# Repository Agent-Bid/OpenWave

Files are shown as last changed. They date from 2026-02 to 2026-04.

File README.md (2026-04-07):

# OpenWave

This is an attempt to make an open-source, modern(ish) digital audio player using commonly available parts today with a simple menu-based operating system shell.

## Firmware Build Instructions

This project uses [PlatformIO](https://platformio.org/) for firmware development. The project is being developed with an ESP32 Devkit V1 (esp32dev).

### Prerequisites
* [PlatformIO CLI](https://docs.platformio.org/en/latest/core/index.html)
* Or [PlatformIO IDE - VSCode](https://docs.platformio.org/en/latest/integration/ide/vscode.html)

### Building
1. Navigate to the firmware directory: `cd Firmware/OpenWave_Firmware`
2. Resolve dependencies and build project: `pio run`

### Uploading
1. Connect the ESP32 board via USB and run: `pio run -t upload`
2. To monitor serial from the board: `pio device monitor`

## Hardware Used
All software tested on:
1. ESP32 Devkit V1
2. Adafruit VS1053b Breakout
3. SSD1306 OLED

Custom 4 layer PCB designed in KiCad
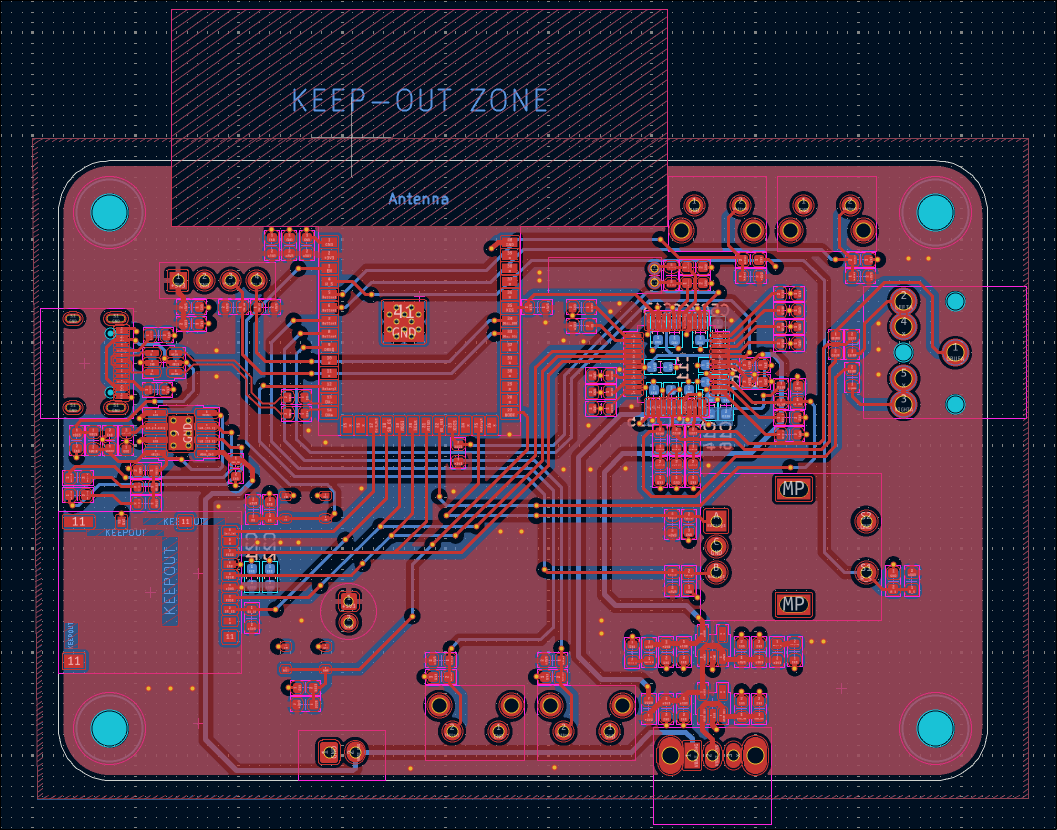
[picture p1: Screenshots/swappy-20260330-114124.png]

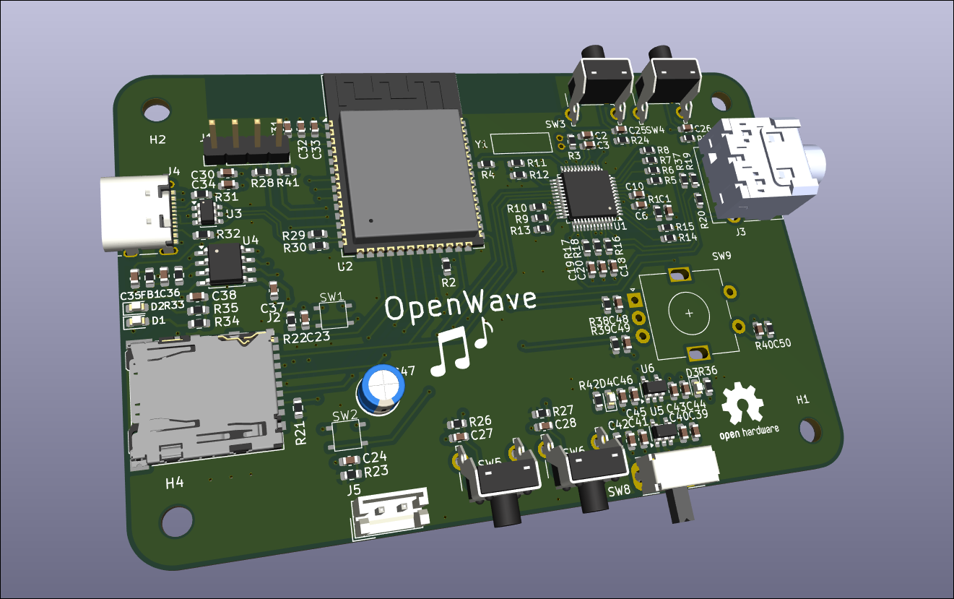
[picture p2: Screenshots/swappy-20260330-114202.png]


## Assembled Board
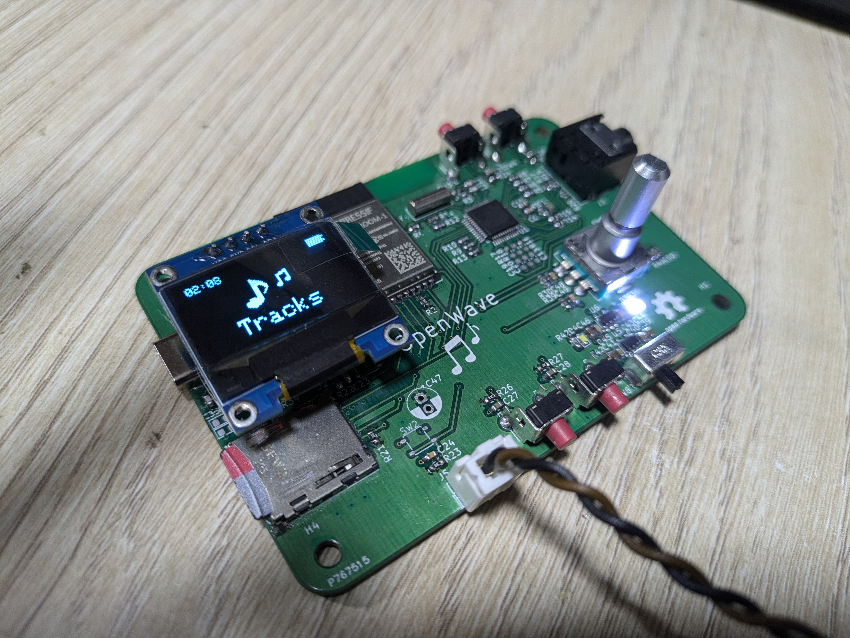
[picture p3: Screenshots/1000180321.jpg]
Assembled 1

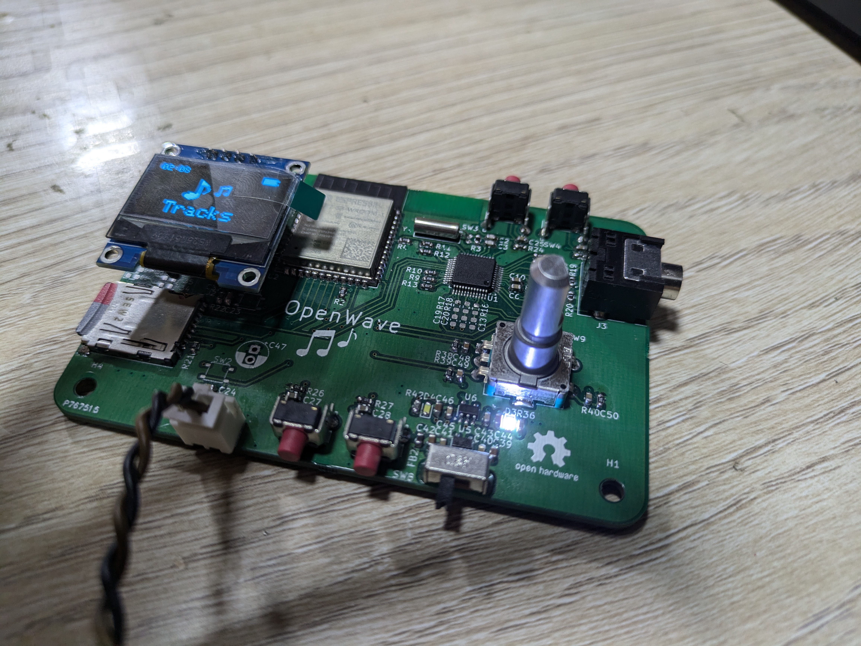
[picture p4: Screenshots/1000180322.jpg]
Assembled 2

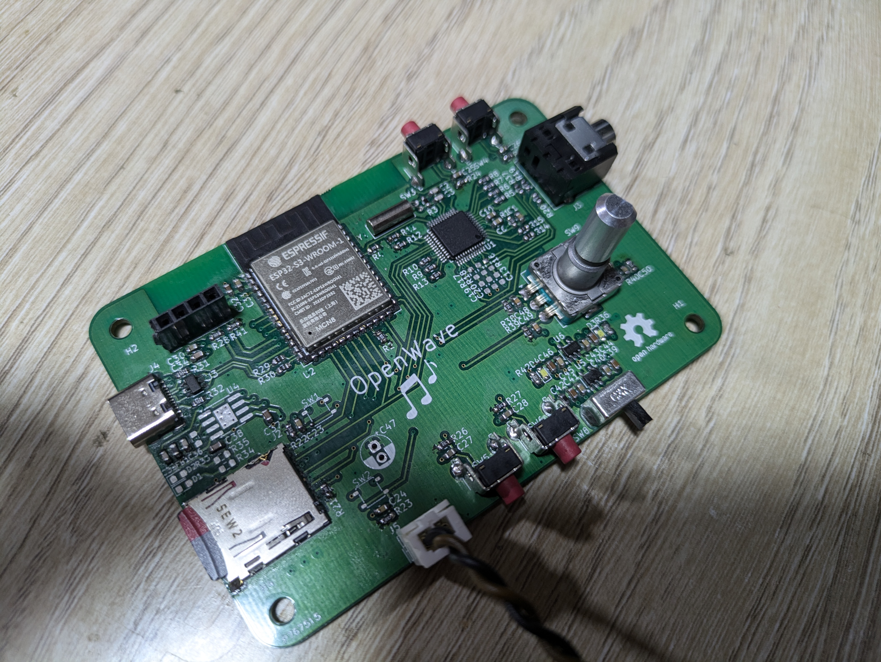
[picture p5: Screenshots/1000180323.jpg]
Assembled 3


## Licensing

This is an open-source hardware project. To ensure all aspects of the design are properly protected and freely shareable, the project uses multiple licenses:

* **Software/Firmware:** All code in this repository is licensed under the [MIT License](LICENSE).
* **Hardware/Electronics:** The KiCad schematics and PCB layout files are licensed under the [CERN Open Hardware Licence Version 2 - Strongly Reciprocal (CERN-OHL-S)](LICENSE-HARDWARE.txt).
* **Documentation & Enclosure:** All documentation and the 3D-printable enclosure models (STEP and STL files) are licensed under [Creative Commons Attribution-ShareAlike 4.0 International (CC-BY-SA 4.0)](LICENSE-DOCS.txt).

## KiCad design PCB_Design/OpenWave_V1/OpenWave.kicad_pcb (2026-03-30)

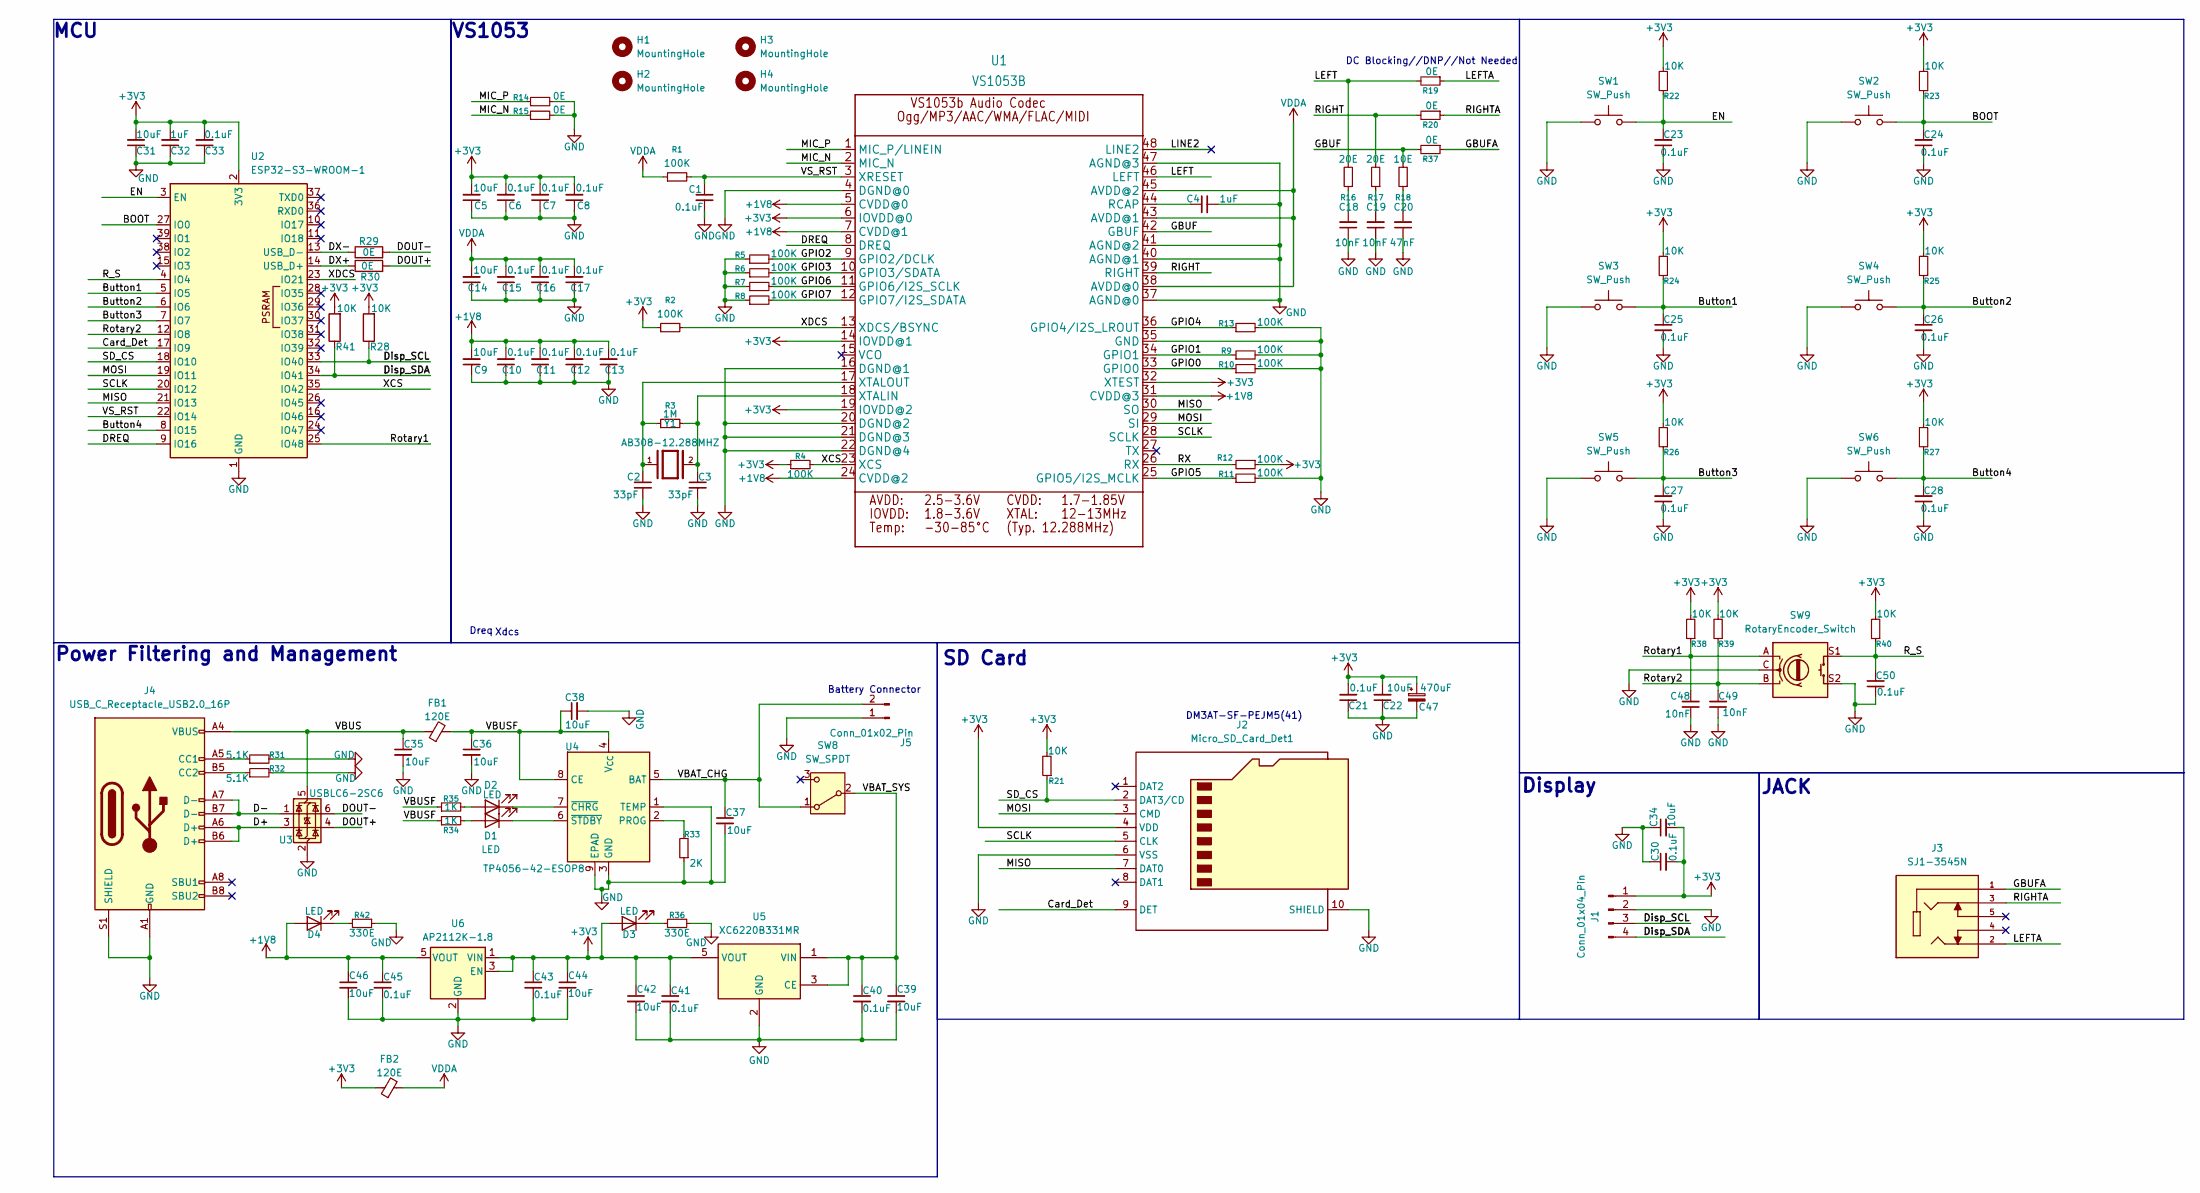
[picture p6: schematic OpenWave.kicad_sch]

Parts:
C1, C6, C7, C8, C10, C11, C12, C13, C15, C16, C17, C21, C23, C24, C25, C26, C27, C28, C30, C33, C40, C41, C43, C45, C50: 0.1uF; C_0603_1608Metric
C2, C3: 33pF; C_0603_1608Metric
C4, C32: 1uF; C_0603_1608Metric
C5, C9, C14, C22, C31, C34, C35, C36, C37, C38, C39, C42, C44, C46: 10uF; C_0603_1608Metric
C18, C19, C48, C49: 10nF; C_0603_1608Metric
C20: 47nF; C_0603_1608Metric
C47: 470uF; CP_Radial_D5.0mm_P2.00mm
D1, D2, D3, D4: LED; LED_0603_1608Metric
FB1, FB2: 120E; R_0603_1608Metric
H1, H2, H3, H4: MountingHole; MountingHole_3.2mm_M3
J1: Conn_01x04_Pin; PinHeader_1x04_P2.54mm_Vertical
J2: Micro_SD_Card_Det1; microSD_HC_Hirose_DM3AT-SF-PEJM5
J3: SJ1-3545N; CUI_SJ1-3545N; PARTREV 1.03
J4: USB_C_Receptacle_USB2.0_16P; USB_C_Receptacle_XKB_U262-16XN-4BVC11
J5: Conn_01x02_Pin; JST_EH_B2B-EH-A_1x02_P2.50mm_Vertical
R1, R2, R4, R5, R6, R7, R8, R9, R10, R11, R12, R13: 100K; R_0603_1608Metric
R3: 1M; R_0603_1608Metric
R14, R15, R19, R20, R29, R30, R37: 0E; R_0603_1608Metric
R16, R17: 20E; R_0603_1608Metric
R18: 10E; R_0603_1608Metric
R21, R22, R23, R24, R25, R26, R27, R28, R38, R39, R40, R41: 10K; R_0603_1608Metric
R31, R32: 5.1K; R_0603_1608Metric
R33: 2K; R_0603_1608Metric
R34, R35: 1K; R_0603_1608Metric
R36, R42: 330E; R_0603_1608Metric
SW1, SW2: SW_Push; TS3315A
SW3, SW4, SW5, SW6: SW_Push; SW_Tactile_SPST_Angled_PTS645Vx58-2LFS
SW8: SW_SPDT; SW_Slide_SPDT_Angled_CK_OS102011MA1Q
SW9: RotaryEncoder_Switch; RotaryEncoder_Alps_EC11E-Switch_Vertical_H20mm
U1: VS1053B; LQFP-48_7x7mm_P0.5mm
U2: ESP32-S3-WROOM-1
U3: USBLC6-2SC6; SOT-23-6
U4: TP4056-42-ESOP8; SOIC-8-1EP_3.9x4.9mm_P1.27mm_EP2.41x3.3mm_ThermalVias
U5: XC6220B331MR; SOT-23-5
U6: AP2112K-1.8; SOT-23-5
Y1: AB308-12.288MHZ; XTAL_AB308-12.288MHZ

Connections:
+1V8: C9.2, C10.2, C11.2, C12.2, C13.2, C45.1, C46.1, D4.2 (A), U1.5 (CVDD@0), U1.7 (CVDD@1), U1.24 (CVDD@2), U1.31 (CVDD@3), U6.5 (VOUT)
+3V3: C5.2, C6.2, C7.2, C8.2, C21.2, C22.2, C30.2, C31.2, C32.2, C33.2, C34.2, C41.1, C42.1, C43.1, C44.1, C47.1, D3.2 (A), FB2.1, J1.1, J2.4 (VDD), R2.1, R4.1, R12.1, R21.2, R22.2, R23.2, R24.2, R25.2, R26.2, R27.2, R28.2, R38.2, R39.2, R40.2, R41.2, U1.6 (IOVDD@0), U1.14 (IOVDD@1), U1.19 (IOVDD@2), U1.32 (XTEST), U2.2 (3V3), U5.5 (VOUT), U6.1 (VIN), U6.3 (EN)
/BOOT: C24.2, R23.1, SW2.2, U2.27 (IO0)
/Button1: C25.2, R24.1, SW3.2, U2.5 (IO5)
/Button2: C26.2, R25.1, SW4.2, U2.6 (IO6)
/Button3: C27.2, R26.1, SW5.2, U2.7 (IO7)
/Button4: C28.2, R27.1, SW6.2, U2.8 (IO15)
/Card_Det: J2.9 (DET), U2.17 (IO9)
/D+: J4.A6 (D+), J4.B6 (D+), U3.3 (I/O2)
/D-: J4.A7 (D-), J4.B7 (D-), U3.1 (I/O1)
/DOUT+: R30.2, U3.4 (I/O2)
/DOUT-: R29.2, U3.6 (I/O1)
/DREQ: U1.8 (DREQ), U2.9 (IO16)
/DX+: R30.1, U2.14 (USB_D+)
/DX-: R29.1, U2.13 (USB_D-)
/Disp_SCL: J1.3, R28.1, U2.33 (IO40)
/Disp_SDA: J1.4, R41.1, U2.34 (IO41)
/EN: C23.2, R22.1, SW1.2, U2.3 (EN)
/GBUF: R18.2, R37.2, U1.42 (GBUF)
/GBUFA: J3.1, R37.1
/GPIO0: R10.1, U1.33 (GPIO0)
/GPIO1: R9.1, U1.34 (GPIO1)
/GPIO2: R5.2, U1.9 (GPIO2/DCLK)
/GPIO3: R6.2, U1.10 (GPIO3/SDATA)
/GPIO4: R13.1, U1.36 (GPIO4/I2S_LROUT)
/GPIO5: R11.1, U1.25 (GPIO5/I2S_MCLK)
/GPIO6: R7.2, U1.11 (GPIO6/I2S_SCLK)
/GPIO7: R8.2, U1.12 (GPIO7/I2S_SDATA)
/LEFT: R16.2, R19.2, U1.46 (LEFT)
/LEFTA: J3.2, R19.1
/LINE2: U1.48 (LINE2)
/MIC_N: R15.1, U1.2 (MIC_N)
/MIC_P: R14.1, U1.1 (MIC_P/LINEIN)
/MISO: J2.7 (DAT0), U1.30 (SO), U2.21 (IO13)
/MOSI: J2.3 (CMD), U1.29 (SI), U2.19 (IO11)
/RIGHT: R17.2, R20.2, U1.39 (RIGHT)
/RIGHTA: J3.3, R20.1
/RX: R12.2, U1.26 (RX)
/R_S: C50.2, R40.1, SW9.S1, U2.4 (IO4)
/Rotary1: C48.2, R38.1, SW9.A, U2.25 (IO48)
/Rotary2: C49.2, R39.1, SW9.B, U2.12 (IO8)
/SCLK: J2.5 (CLK), U1.28 (SCLK), U2.20 (IO12)
/SD_CS: J2.2 (DAT3/CD), R21.1, U2.18 (IO10)
/VBAT_CHG: C37.1, J5.2, SW8.1 (A), U4.5 (BAT)
/VBAT_SYS: C39.1, C40.1, SW8.2 (B), U5.1 (VIN), U5.3 (CE)
/VBUS: C35.1, FB1.1, J4.A4 (VBUS), J4.A9 (VBUS), J4.B4 (VBUS), J4.B9 (VBUS), U3.5 (VBUS)
/VBUSF: C36.1, C38.1, FB1.2, R34.1, R35.1, U4.4 (V_{CC}), U4.8 (CE)
/VS_RST: C1.1, R1.2, U1.3 (XRESET), U2.22 (IO14)
/XCS: R4.2, U1.23 (XCS), U2.35 (IO42)
/XDCS: R2.2, U1.13 (XDCS/BSYNC), U2.23 (IO21)
GND: C1.2, C2.2, C3.2, C4.2, C5.1, C6.1, C7.1, C8.1, C9.1, C10.1, C11.1, C12.1, C13.1, C14.1, C15.1, C16.1, C17.1, C18.1, C19.1, C20.1, C21.1, C22.1, C23.1, C24.1, C25.1, C26.1, C27.1, C28.1, C30.1, C31.1, C32.1, C33.1, C34.1, C35.2, C36.2, C37.2, C38.2, C39.2, C40.2, C41.2, C42.2, C43.2, C44.2, C45.2, C46.2, C47.2, C48.1, C49.1, C50.1, J1.2, J2.6 (VSS), J2.10 (SHIELD), J4.A1 (GND), J4.A12 (GND), J4.B1 (GND), J4.B12 (GND), J4.S1 (SHIELD), J5.1, R5.1, R6.1, R7.1, R8.1, R9.2, R10.2, R11.2, R13.2, R14.2, R15.2, R31.2, R32.2, R33.1, R36.1, R42.1, SW1.1, SW2.1, SW3.1, SW4.1, SW5.1, SW6.1, SW9.C, SW9.S2, U1.4 (DGND@0), U1.16 (DGND@1), U1.20 (DGND@2), U1.21 (DGND@3), U1.22 (DGND@4), U1.35 (GND), U1.37 (AGND@0), U1.40 (AGND@1), U1.41 (AGND@2), U1.47 (AGND@3), U2.1 (GND), U2.40 (GND), U2.41 (GND), U3.2 (GND), U4.1 (TEMP), U4.3 (GND), U4.9 (EPAD), U5.2 (GND), U6.2 (GND)
unnamed: C18.2, R16.1
unnamed: C19.2, R17.1
unnamed: C20.2, R18.1
unnamed: D1.2 (A), R34.2
unnamed: D1.1 (K), U4.6 (~STDBY)
unnamed: D2.2 (A), R35.2
unnamed: D2.1 (K), U4.7 (~CHRG)
unnamed: D3.1 (K), R36.2
unnamed: D4.1 (K), R42.2
unnamed: J4.A5 (CC1), R31.1
unnamed: J4.B5 (CC2), R32.1
unnamed: C4.1, U1.44 (RCAP)
unnamed: C3.1, R3.2, U1.18 (XTALIN), Y1.2
unnamed: C2.1, R3.1, U1.17 (XTALOUT), Y1.1
unnamed: R33.2, U4.2 (PROG)
VDDA: C14.2, C15.2, C16.2, C17.2, FB2.2, R1.1, U1.38 (AVDD@0), U1.43 (AVDD@1), U1.45 (AVDD@2)

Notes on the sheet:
DM3AT-SF-PEJM5(41)
Display
Battery Connector
Dreq
MCU
SD Card
DC Blocking//DNP//Not Needed
Xdcs
Power Filtering and Management
VS1053
JACK

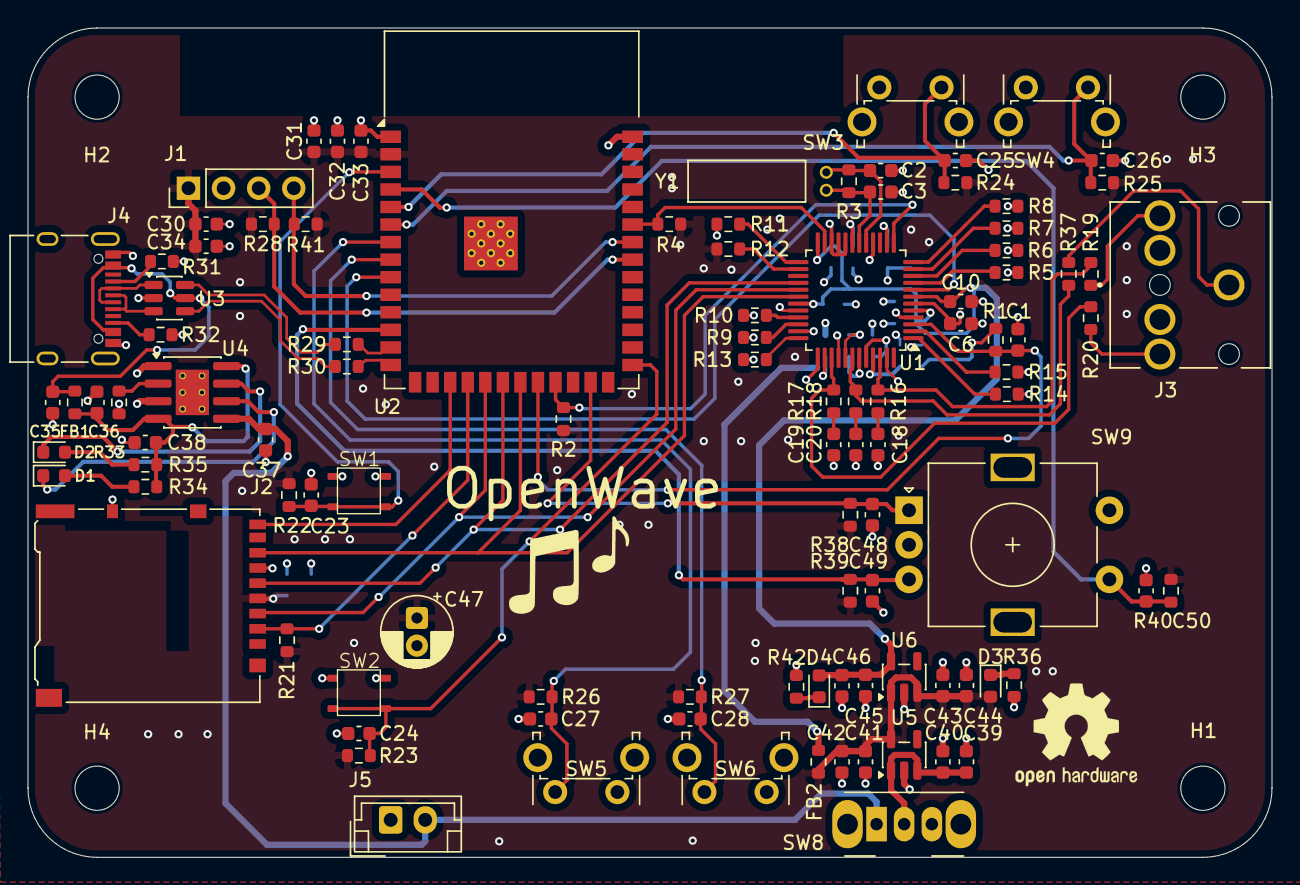
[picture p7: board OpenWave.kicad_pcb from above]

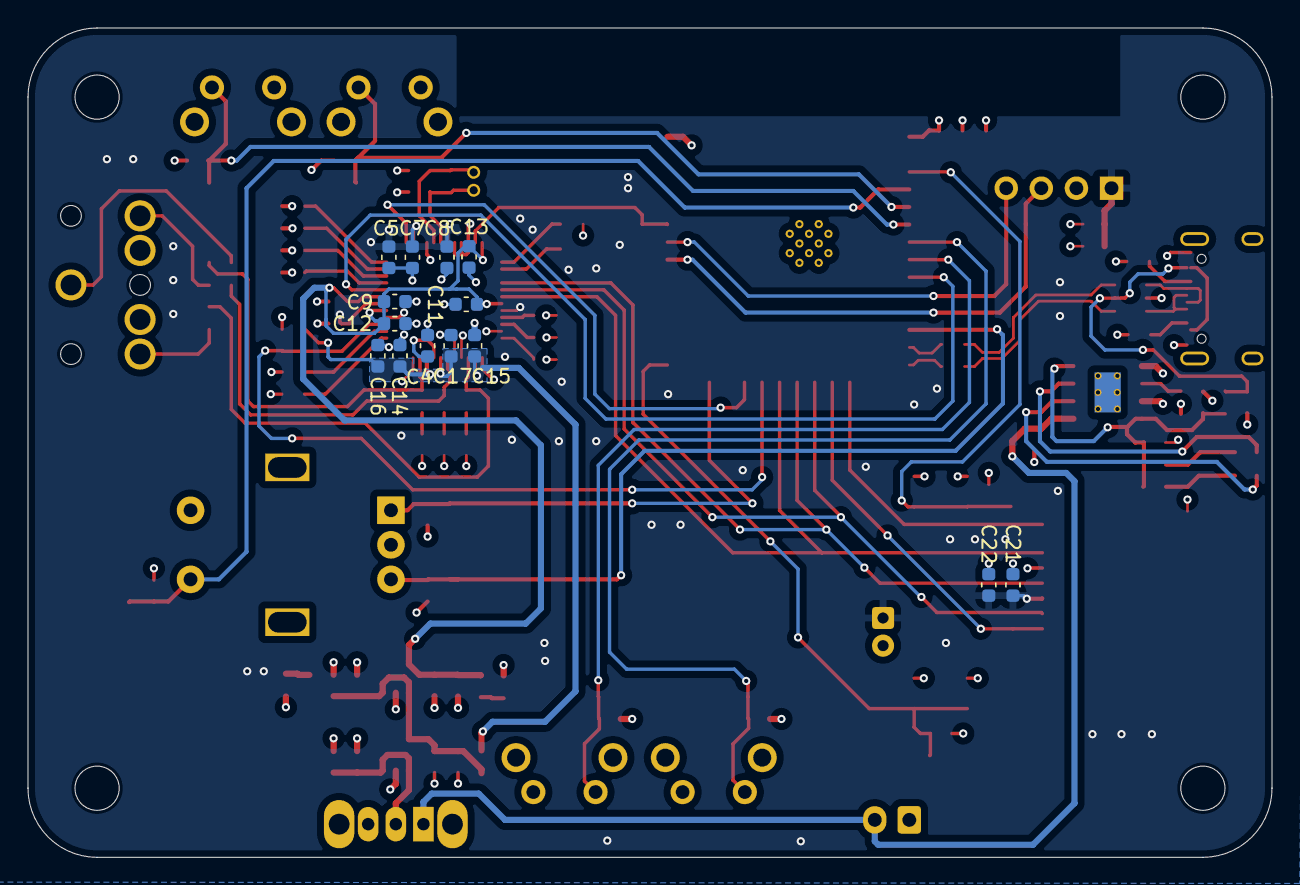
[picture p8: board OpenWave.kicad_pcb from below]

Board: 4 copper layers, 90.0 x 60.0 mm, 121 parts (14 on the bottom side), 66 nets.

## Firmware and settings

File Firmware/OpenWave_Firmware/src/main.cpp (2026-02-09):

#include <Adafruit_GFX.h>
#include <Adafruit_SSD1306.h>
#include <Adafruit_VS1053.h>
#include <Arduino.h>
#include <PowerManagement.h>
#include <Preferences.h>
#include <SD.h>
#include <SPI.h>
#include <WiFi.h>
#include <Wire.h>
#include <cstdlib>
#include <iostream>
#include <secrets.h>
#include <symbols.h>
#include <time.h>

#define SCREEN_WIDTH 128
#define SCREEN_HEIGHT 64
#define SDCS 5
#define XDCS 4
#define CS 33
#define RESET 15
#define DREQ 35

int selectbutton = 25;
int backbutton = 26;
int pausebutton = 27;
int downbutton = 13;
int PassedTime;
int menucounter = 0;
int settingscounter = 0;
int tracksfound = 0;
int trackselectindex = 0;
int buttondelay = 150;
int lastselectstate = LOW;
int lastbackstate = LOW;
int lastpausestate = LOW;
int lastdownstate = LOW;
int menustartindex = 0;
int tracksperscreen = 5;
int currentsongduration = 0;
int eqmenuindex = 0;
int bassamp = 15;         // Default Sound Settings
int trebleamp = 6;        // Default Sound Settings
int bassfreq = 12;        // Default Sound Settings
int treblefreq = 10;      // Default Sound Settings
int leftchannelvol = 10;  // Default Sound Settings
int rightchannelvol = 10; // Default Sound Settings
bool wifirequest;
unsigned long lastcheck = 0;
unsigned long lastbuttontime = 0;
unsigned long screenupdate = 0;
const TickType_t xDelay = 500 / portTICK_PERIOD_MS;
unsigned char playerstate;
char currentsongname[200];
char tracklist[50][30];
char buffer[50];
File root;
const char *ntpserver = "pool.ntp.org";
const long gmtoffset = 19800;
const long daylightoffset = 0;
enum { home, song, tracks, stopped, settingsmenu, equalizermenu };

Adafruit_VS1053_FilePlayer walkman =
    Adafruit_VS1053_FilePlayer(RESET, CS, XDCS, DREQ, SDCS);
Adafruit_SSD1306 display(SCREEN_WIDTH, SCREEN_HEIGHT, &Wire, -1);

void timekeeper();
void trackmenu();
void playersettings();
void populatetracklist();
void trackselector();
void equalizer();
void equalizerfunc();
void networkmanager(void *parameter);

void setup() {
  Serial.begin(9600);
  if (!display.begin(SSD1306_SWITCHCAPVCC, 0x3C)) {
    Serial.println(F("Display Not Found"));
    for (;;)
      ;
  }
  pinMode(selectbutton, INPUT);
  pinMode(backbutton, INPUT);
  pinMode(downbutton, INPUT);
  pinMode(pausebutton, INPUT);
  display.clearDisplay();
  display.setTextSize(1);
  display.setTextColor(WHITE);
  display.setCursor(0, 0);
  display.println(F("Testing Audio Systems"));
  if (!walkman.begin()) {
    display.println(F("Audio Systems Malfunctioning"));
    display.display();
    for (;;)
      ;
  } else {
    display.println(F("Audio Systems Functional"));
  }
  walkman.setVolume(leftchannelvol, rightchannelvol);
  // walkman.useInterrupt(DREQ);
  display.println(F("Testing SD Card"));
  if (SD.begin(5, SPI, 4000000)) {
    display.println(F("SD card found"));
  } else {
    display.println(F("SD card not found"));
    display.display();
    // for(;;);
  }
  TaskHandle_t xHandle = NULL;
  xTaskCreatePinnedToCore(networkmanager, "WiFiCheck", 4000, NULL, 0, &xHandle,
                          0);
  wifirequest = true;
  display.println(F("ESP Walkman V1"));
  display.display();
}

void homescreen() {
  struct tm timeinfo;
  display.clearDisplay();
  display.setTextSize(1);
  display.setTextColor(WHITE);
  display.setCursor(2, 0);
  if (getLocalTime(&timeinfo, 0)) {
    display.printf("%02d:%02d", timeinfo.tm_hour, timeinfo.tm_min);
  } else {
    display.println("Time Syncing");
  }
  display.drawBitmap(110, 0, battery, 16, 8, WHITE);
  if (menucounter == 0) {
    display.drawBitmap(35, 13, musicnote1, 32, 32, WHITE);
    display.drawBitmap(60, 10, musicnote2, 32, 32, WHITE);
    display.setCursor(25, 45);
    display.setTextSize(2);
    display.println(F("Tracks"));
    display.display();
  } else {
    display.drawCircle(4, 18, 2, WHITE);
    display.setCursor(10, 15);
    display.println(F("View Library"));
    display.fillCircle(4, 27, 2, WHITE);
    display.setCursor(10, 24);
    display.println(F("Settings"));
    display.display();
  }
}

void updatescreen() {
  display.clearDisplay();
  display.setTextSize(1);
  display.setTextColor(WHITE);
  display.setCursor(0, 0);
  display.println(F("Now Playing: "));
  display.setTextSize(1);
  display.setCursor(0, 15);
  display.println(currentsongname + 1);

  int currentminutes = PassedTime / 60;
  int currentseconds = PassedTime % 60;

  display.setTextSize(1);
  display.setCursor(0, 35);
  if (currentminutes < 10)
    display.print("0");
  display.print(currentminutes);
  display.print(":");
  if (currentseconds < 10)
    display.print("0");
  display.print(currentseconds);
  display.print(F(" / "));

  int totalminutes = currentsongduration / 60;
  int totalseconds = currentsongduration % 60;
  display.print(totalminutes);
  display.print(':');
  if (totalseconds < 10)
    display.print("0");
  display.print(totalseconds);

  int bars = 16;
  int spacing = 2;
  int barwidth = (128 - (bars * spacing)) / bars;

  for (int i = 0; i < bars; i++) {
    int height = random(2, 20);
    int x = i * (barwidth + spacing);
    int y = 64 - height;
    display.fillRect(x, y, barwidth, height, WHITE);
  }
  display.display();
}

void paused() {}

void timekeeper() {
  if (millis() - lastcheck > 1000) {
    lastcheck = millis();
    if (PassedTime < currentsongduration) {
      PassedTime++;
    } else {
      PassedTime = 0;
    }
  }
  if (millis() - screenupdate > 85) {
    screenupdate = millis();
    updatescreen();
  }
}

void trackmenu() {
  int y = 15;
  display.clearDisplay();
  display.setCursor(0, 0);
  display.setTextSize(1);
  display.setTextColor(WHITE);
  display.println("Your Tracks: ");
  display.setCursor(0, 15);
  for (int x = menustartindex; x < (tracksperscreen + menustartindex); x++) {
    if (x >= tracksfound) {
      break;
    }
    display.setCursor(0, y);
    if (x == trackselectindex) {
      display.print(">");
    } else {
      display.print(" ");
    }
    strcpy(buffer, tracklist[x]);
    if (strlen(buffer) > 18) {
      buffer[15] = '.';
      buffer[16] = '.';
      buffer[17] = '.';
      buffer[18] = '\0';
    }
    display.println(buffer);
    y += 10;
  }
  display.display();
}

void populatetracklist() {
  tracksfound = 0;
  File root = SD.open("/");
  if (!root) {
    display.clearDisplay();
    display.setCursor(0, 0);
    display.println(F("SD Error"));
    display.display();
    return;
  }
  root.rewindDirectory();
  while (true) {
    File entry = root.openNextFile();
    if (!entry) {
      break;
    }
    if (entry.isDirectory()) {
      entry.close();
      continue;
    }
    strncpy(tracklist[tracksfound], entry.name(), 29);
    tracklist[tracksfound][29] = '\0';
    tracksfound++;
    if (tracksfound >= 50) {
      break;
    }
    entry.close();
  }
  root.close();
}

void playersettings() {
  display.clearDisplay();
  display.setTextSize(1);
  display.setTextColor(WHITE);
  display.setCursor(0, 0);
  display.println(F("Settings"));
  if (settingscounter == 0) {
    display.fillCircle(4, 18, 2, WHITE);
    display.setCursor(10, 15);
    display.println(F("Bluetooth"));
    display.drawCircle(4, 27, 2, WHITE);
    display.setCursor(10, 24);
    display.println(F("WiFi"));
    display.drawCircle(4, 36, 2, WHITE);
    display.setCursor(10, 33);
    display.println("Equalizer");
    display.display();
  } else if (settingscounter == 1) {
    display.drawCircle(4, 18, 2, WHITE);
    display.setCursor(10, 15);
    display.println(F("Bluetooth"));
    display.fillCircle(4, 27, 2, WHITE);
    display.setCursor(10, 24);
    display.println(F("WiFi"));
    display.drawCircle(4, 36, 2, WHITE);
    display.setCursor(10, 33);
    display.println("Equalizer");
    display.display();
  } else {
    display.drawCircle(4, 18, 2, WHITE);
    display.setCursor(10, 15);
    display.println(F("Bluetooth"));
    display.drawCircle(4, 27, 2, WHITE);
    display.setCursor(10, 24);
    display.println(F("WiFi"));
    display.fillCircle(4, 36, 2, WHITE);
    display.setCursor(10, 33);
    display.println("Equalizer");
    display.display();
  }
}

void networkmanager(void *parameter) {
  for (;;) {
    if (wifirequest == true) {
      WiFi.begin(WIFI_SSID, WIFI_PASS);
      int recount = 0;
      while (WiFi.status() != WL_CONNECTED && recount < 10) {
        Serial.println(".");
        vTaskDelay(xDelay);
        recount++;
      }
      Serial.println("WiFi Connected");
      configTime(gmtoffset, daylightoffset, ntpserver);
      struct tm timeinfo;
      if (getLocalTime(&timeinfo)) {
        Serial.println("Time Synced");
      } else {
        Serial.println("Not Connected");
      }
      wifirequest = false;
      WiFi.disconnect(true);
      WiFi.mode(WIFI_OFF);
      Serial.print("water mark : ");
      Serial.println(uxTaskGetStackHighWaterMark(NULL));
    }
    vTaskDelay(100 / portTICK_PERIOD_MS);
  }
}

void trackselector() {
  currentsongname[0] = '\0';
  int i;
  int loopcounter = 0;
  walkman.stopPlaying();
  File root = SD.open("/");
  root.rewindDirectory();
  while (true) {
    File current = root.openNextFile();
    if (!current) {
      break;
    }
    if (current.isDirectory()) {
      current.close();
      continue;
    }
    if (loopcounter == trackselectindex) {
      strcpy(currentsongname, "/");
      strncat(currentsongname, current.name(), 100);
      currentsongname[100] = '\0';
      currentsongduration = current.size() / 32000;
      current.close();
      // walkman.startPlayingFile(currentsongname);
      // current.close();
      break;
    }
    loopcounter++;
    current.close();
  }
  root.close();
  if (strlen(currentsongname) > 0) {
    walkman.softReset();
    equalizerfunc();
    walkman.startPlayingFile(currentsongname);
  }
}

void equalizerfunc() {
  if (bassfreq > 15 || bassfreq < 0) {
    bassfreq = 0;
  }

  if (bassamp > 15 || bassamp < 0) {
    bassamp = 0;
  }

  if (treblefreq > 15 || treblefreq < 0) {
    treblefreq = 0;
  }

  if (trebleamp > 15 || trebleamp < 0) {
    trebleamp = 0;
  }

  if (rightchannelvol < 10) {
    rightchannelvol = 10;
  }

  if (rightchannelvol > 50) {
    rightchannelvol = 50;
  }

  if (leftchannelvol < 10) {
    leftchannelvol = 10;
  }

  if (leftchannelvol > 50) {
    leftchannelvol = 50;
  }

  uint16_t eqstats = ((trebleamp & 0xF) << 12 | (treblefreq & 0xF) << 8 |
                      (bassamp & 0xF) << 4 | (bassfreq & 0xF));
  walkman.sciWrite(2, eqstats);
}

void equalizer() {

  if (eqmenuindex == 0) {
    display.clearDisplay();
    display.setCursor(0, 0);
    display.println(F("Equalizer"));
    display.fillCircle(4, 18, 2, WHITE);
    display.setCursor(10, 15);
    display.println(F("Bass Amp: "));
    display.setCursor(62, 15);
    display.print(bassamp);
    display.drawCircle(4, 27, 2, WHITE);
    display.setCursor(10, 24);
    display.println(F("Treble Amp: "));
    display.setCursor(75, 24);
    display.print(trebleamp);
    display.drawCircle(4, 36, 2, WHITE);
    display.setCursor(10, 33);
    display.println(F("Bass Frequency: "));
    display.setCursor(98, 33);
    display.print(bassfreq);
    display.drawCircle(4, 45, 2, WHITE);
    display.setCursor(10, 42);
    display.println(F("Treble Frequency: "));
    display.setCursor(110, 42);
    display.print(treblefreq);
    display.drawCircle(4, 54, 2, WHITE);
    display.setCursor(10, 51);
    display.println(F("Volume: "));
    display.setCursor(53, 51);
    display.print(rightchannelvol);
    display.display();
  } else if (eqmenuindex == 1) {
    display.clearDisplay();
    display.setCursor(0, 0);
    display.println(F("Equalizer"));
    display.drawCircle(4, 18, 2, WHITE);
    display.setCursor(10, 15);
    display.println(F("Bass Amp: "));
    display.setCursor(62, 15);
    display.print(bassamp);
    display.fillCircle(4, 27, 2, WHITE);
    display.setCursor(10, 24);
    display.println(F("Treble Amp: "));
    display.setCursor(75, 24);
    display.print(trebleamp);
    display.drawCircle(4, 36, 2, WHITE);
    display.setCursor(10, 33);
    display.println(F("Bass Frequency: "));
    display.setCursor(98, 33);
    display.print(bassfreq);
    display.drawCircle(4, 45, 2, WHITE);
    display.setCursor(10, 42);
    display.println(F("Treble Frequency: "));
    display.setCursor(110, 42);
    display.print(treblefreq);
    display.drawCircle(4, 54, 2, WHITE);
    display.setCursor(10, 51);
    display.println(F("Volume: "));
    display.setCursor(53, 51);
    display.print(rightchannelvol);
    display.display();
  } else if (eqmenuindex == 2) {
    display.clearDisplay();
    display.setCursor(0, 0);
    display.println(F("Equalizer"));
    display.drawCircle(4, 18, 2, WHITE);
    display.setCursor(10, 15);
    display.println(F("Bass Amp: "));
    display.setCursor(62, 15);
    display.print(bassamp);
    display.drawCircle(4, 27, 2, WHITE);
    display.setCursor(10, 24);
    display.println(F("Treble Amp: "));
    display.setCursor(75, 24);
    display.print(trebleamp);
    display.fillCircle(4, 36, 2, WHITE);
    display.setCursor(10, 33);
    display.println(F("Bass Frequency: "));
    display.setCursor(98, 33);
    display.print(bassfreq);
    display.drawCircle(4, 45, 2, WHITE);
    display.setCursor(10, 42);
    display.println(F("Treble Frequency: "));
    display.setCursor(110, 42);
    display.print(treblefreq);
    display.drawCircle(4, 54, 2, WHITE);
    display.setCursor(10, 51);
    display.println(F("Volume: "));
    display.setCursor(53, 51);
    display.print(rightchannelvol);
    display.display();
  } else if (eqmenuindex == 3) {
    display.clearDisplay();
    display.setCursor(0, 0);
    display.println(F("Equalizer"));
    display.drawCircle(4, 18, 2, WHITE);
    display.setCursor(10, 15);
    display.println(F("Bass Amp: "));
    display.setCursor(62, 15);
    display.print(bassamp);
    display.drawCircle(4, 27, 2, WHITE);
    display.setCursor(10, 24);
    display.println(F("Treble Amp: "));
    display.setCursor(75, 24);
    display.print(trebleamp);
    display.drawCircle(4, 36, 2, WHITE);
    display.setCursor(10, 33);
    display.println(F("Bass Frequency: "));
    display.setCursor(98, 33);
    display.print(bassfreq);
    display.fillCircle(4, 45, 2, WHITE);
    display.setCursor(10, 42);
    display.println(F("Treble Frequency: "));
    display.setCursor(110, 42);
    display.print(treblefreq);
    display.drawCircle(4, 54, 2, WHITE);
    display.setCursor(10, 51);
    display.println(F("Volume: "));
    display.setCursor(53, 51);
    display.print(rightchannelvol);
    display.display();
  } else if (eqmenuindex == 4) {
    display.clearDisplay();
    display.setCursor(0, 0);
    display.println(F("Equalizer"));
    display.drawCircle(4, 18, 2, WHITE);
    display.setCursor(10, 15);
    display.println(F("Bass Amp: "));
    display.setCursor(62, 15);
    display.print(bassamp);
    display.drawCircle(4, 27, 2, WHITE);
    display.setCursor(10, 24);
    display.println(F("Treble Amp: "));
    display.setCursor(75, 24);
    display.print(trebleamp);
    display.drawCircle(4, 36, 2, WHITE);
    display.setCursor(10, 33);
    display.println(F("Bass Frequency: "));
    display.setCursor(98, 33);
    display.print(bassfreq);
    display.drawCircle(4, 45, 2, WHITE);
    display.setCursor(10, 42);
    display.println(F("Treble Frequency: "));
    display.setCursor(110, 42);
    display.print(treblefreq);
    display.fillCircle(4, 54, 2, WHITE);
    display.setCursor(10, 51);
    display.println(F("Volume: "));
    display.setCursor(53, 51);
    display.print(rightchannelvol);
    display.display();
  }
  equalizerfunc();
}
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

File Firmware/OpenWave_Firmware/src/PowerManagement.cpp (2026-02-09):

#include <Adafruit_SSD1306.h>
#include <Adafruit_VS1053.h>
#include <PowerManagement.h>
#include <time.h>

// Function for power management and system sleep.

extern Adafruit_SSD1306 display;
extern Adafruit_VS1053_FilePlayer walkman;
extern int pausebutton;
extern int selectbutton;
extern int downbutton;
extern int backbutton;
boolean manageractive = false;
boolean isdrawn = false;

unsigned long lastactivitytime = 0;
unsigned long sleeptime = 10000;

void initpowermanager() {
  lastactivitytime = millis();
  manageractive = true;
}

void sleeptimereset() {
  if (digitalRead(pausebutton) == HIGH || digitalRead(selectbutton) == HIGH ||
      digitalRead(downbutton) == HIGH || digitalRead(backbutton) == HIGH) {
    lastactivitytime = millis();
    display.dim(false);
    isdrawn = false;
  }
}

void sleeping() {
  if ((millis() - lastactivitytime) >= sleeptime &&
      walkman.playingMusic == false) {
    if (isdrawn == false) {
      display.setCursor(25, 25);
      display.setTextSize(2);
      //display.print(F("Sleeping"));
      display.display();
      isdrawn = true;
    }
    display.dim(true);
  } else if ((millis() - lastactivitytime) >= sleeptime &&
             walkman.playingMusic == true) {
    if (isdrawn == false) {
      display.setCursor(25, 25);
      display.setTextSize(2);
      //display.print(F("Sleeping"));
      display.display();
      isdrawn = true;
    }
    display.dim(true);
  }
}

/*void wakefromsleep() {
  if ((millis() - lastactivitytime) >= sleeptime &&
          (digitalRead(pausebutton) == HIGH ||
      digitalRead(selectbutton) == HIGH || digitalRead(downbutton) == HIGH ||
      digitalRead(backbutton) == HIGH)) {
    lastactivitytime = millis();
    display.dim(false);
  }
}*/

void powermanager() {
  if (manageractive == false) {
    initpowermanager();
    sleeptimereset();
    sleeping();
  } else if (manageractive == true) {
    sleeptimereset();
    sleeping();
  }
}

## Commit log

2025-12-06 Switched to RAM buffered UI for track selection
2025-12-10 Implemented scrollable tracks menu and improved memory allocation on track selection menu
2025-12-20 Minor bug fixes with the song selection and looping logic. Tested with Codec
    [main.cpp]
2025-12-20 Made tweaks to the state machine, added song switching in pause and track switching in the song state.
2025-12-27 Initialized PCB Design and added cut off frequency options to the equalizer.
    [WalkmanPCB_V1.kicad_pcb, WalkmanPCB_V1.kicad_sch]
2026-01-01 Updated schematics with a headphone amp. WIP
    [WalkmanPCB_V1.kicad_pcb, WalkmanPCB_V1.kicad_sch]
2026-01-06 Basic power management code(sleep when inactive)
2026-01-10 Refactored power manager, changed headphone amp to PAM8908 in shcematics.
    [WalkmanPCB_V1.kicad_pcb, WalkmanPCB_V1.kicad_sch]
2026-02-01 Basic 3D design of the case, updated pcb dimensions.
    [Case_Proto1.FCStd, WalkmanPCB_V1.kicad_pcb]
2026-02-09 Minor Updates to the Schematics, removed headphone Amp IC
    [WalkmanPCB_V1.kicad_sch]
2026-02-09 Deleted old case designs
    [Case_Proto1.FCStd]
2026-02-18 Updated Routing for PCB
    [WalkmanPCB_V1.kicad_pcb, WalkmanPCB_V1.kicad_sch]
2026-02-18 Updated PCB routing
    [WalkmanPCB_V1.kicad_pcb]
2026-02-21 Completed PCB Design, Updated Licences and Readme.
    [OpenWave.kicad_pcb, OpenWave.kicad_sch]
2026-02-24 Added power indicators and silkscreen
    [OpenWave.kicad_pcb, OpenWave.kicad_sch]
2026-02-25 Minor tracing updates
    [OpenWave.kicad_pcb]
2026-03-09 Updated BOM, Changed ESP pin defs.
    [OpenWave.kicad_pcb, OpenWave.kicad_sch]
2026-03-09 Updated BOM
